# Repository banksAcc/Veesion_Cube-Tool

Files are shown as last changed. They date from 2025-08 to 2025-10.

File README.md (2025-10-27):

# Veesion Cube Tool

A compact hardware and software stack for estimating the pose of a 3D‑printed pen tip.  
An ESP32 inside the pen sends a BLE trigger; the PC listens for the event, grabs a frame from a camera and computes the pen pose from ArUco markers.







## Idea
<div style="display: flex; gap: 20px;">
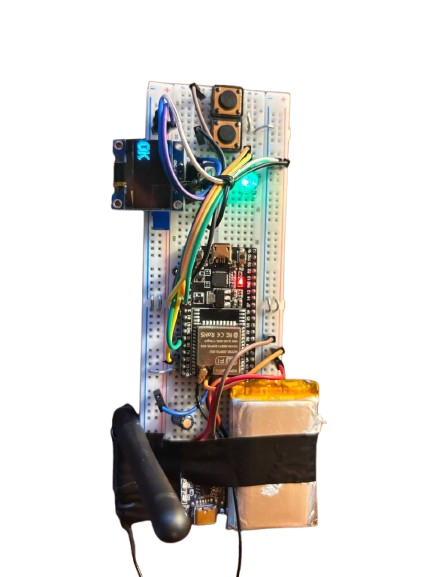
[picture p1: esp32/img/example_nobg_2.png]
Device
  
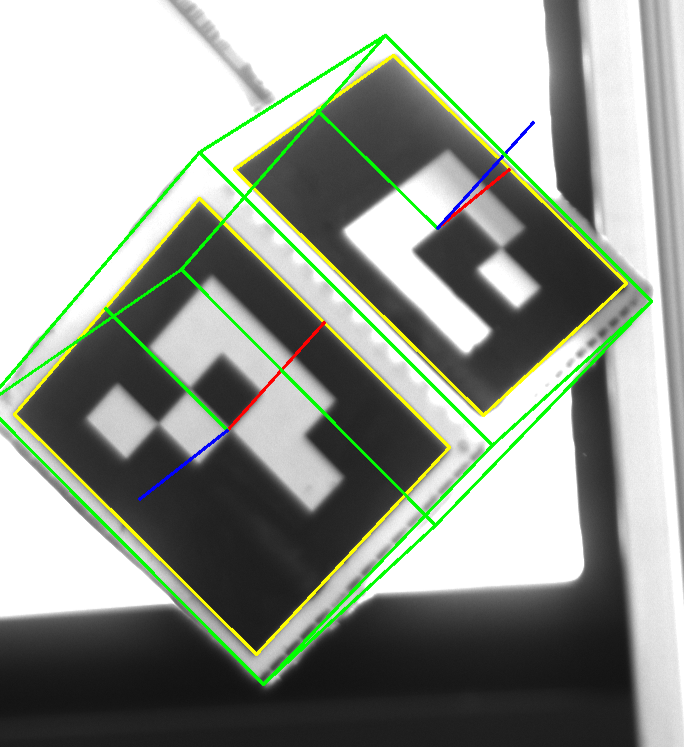
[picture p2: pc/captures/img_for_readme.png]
Cube After
  
</div>
<p align="center">
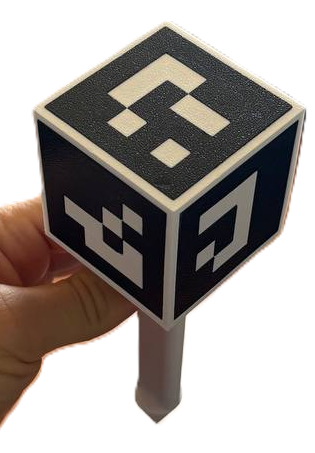
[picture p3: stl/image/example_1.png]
3D pen
  
</p>

## Prerequisites

### Hardware
- **ESP32 DevKit** (BLE + two buttons) to trigger the acquisition
- **Physical assembly**: 3D-printed pen/cube with 3–4 ArUco markers attached
- **Camera**: Basler camera with Pylon drivers installed or a compatible UVC webcam
- **Calibration target**: ChArUco board or checkerboard pattern

### Software
- **Python ≥3.10** and `pip` to install dependencies
- **ESP32 firmware toolchain**: Arduino IDE/CLI or PlatformIO (optional but recommended)
- **Basler Pylon drivers** (optional) for industrial camera integration
- Python libraries from [`pc/app/requirements.txt`](pc/app/requirements.txt)

## Repository structure
- [`esp32/`](esp32/) – BLE firmware for the pen, detailed in [`esp32/README.md`](esp32/README.md)
- [`pc/`](pc/) – PC-side application for capture and pose estimation, see [`pc/README.md`](pc/README.md)
- [`cube_minimal/`](cube_minimal/) – pose estimation library with dataset and tests
- [`cube_minimal/data/sample_dataset/`](cube_minimal/data/sample_dataset/) – sample images referenced in [Quick start](#quick-start)

## Workflow
1. Press a button on the pen. The ESP32 publishes a BLE notification.
2. The PC application receives the trigger and acquires an image from the selected camera.
3. ArUco markers on the cube are detected and the cube pose is estimated.
4. A fixed transform gives the pen‑tip pose, which can be logged or streamed.

### Pose result artifacts

Each capture session produces both a JSON summary and a CSV table beside the
session folder (e.g. `session_<start>__<end>_pose.json` / `.csv`). The JSON file
stores a list of frame objects containing:

* `tvec_tip`: Cartesian tip position expressed in metres relative to the camera.
* `wand_direction`: Normalised tip direction vector in camera coordinates.
* `euler_tip`: Tip orientation expressed as Z‑Y‑Z intrinsic Euler angles
  (`rz1`, `ry`, `rz2`) in radians.
* `tip_pose`: Convenience tuple `(x, y, z, rz1, ry, rz2)` merging position and
  orientation. Downstream consumers should prefer this when available.

The accompanying CSV mirrors the JSON content with one row per frame and the
columns: `frame_index`, `timestamp`, `ok`, `tip_x`, `tip_y`, `tip_z`, `tip_rz1`,
`tip_ry`, `tip_rz2`. Numerical values are emitted in metres/radians to ease data
analysis in spreadsheets or plotting tools.

## Quick start

### Set up the PC environment
```bash
cd pc
python -m venv .venv
source .venv/bin/activate
pip install -r app/requirements.txt
```
```powershell
cd pc
py -m venv .venv
. .\.venv\Scripts\Activate.ps1
pip install -r app\requirements.txt
```
> Tip: keep the virtual environment active for the next steps (`pytest`, CLI, PC application).

### Build & flash the ESP32 firmware
Follow the [Getting Started](esp32/README.md#getting-started) section of the firmware:

1. Install the **NimBLE-Arduino**, **Adafruit SSD1306**, and **Adafruit GFX** libraries via the Arduino Library Manager.
2. Wire the components as described in [`esp32/README.md`](esp32/README.md#connections).
3. Build and upload the project by selecting the **ESP32 Dev Module** board (Arduino IDE/CLI) or set up an equivalent PlatformIO project.

### Calibration and sample dataset
- Use the scripts in [`pc/calib/`](pc/calib/) to produce `calib_data.npz` (camera intrinsics) from a ChArUco/checkerboard target.
- For quick trials, point `capture.test_source_dir` to [`cube_minimal/data/sample_dataset/`](cube_minimal/data/sample_dataset/), which contains the sample images described in its [README](cube_minimal/data/README.md).

### Run the pipeline quickly
```bash
cd pc/app
python app.py
```
Configure [`config.yaml`](pc/app/config.yaml) before launching the application: set `ble.name_prefix` or `ble.addr`, choose the camera (`camera_type`, `camera_id`/`camera_serial`), and provide the calibration path (`pose.camera_calibration_npz`).

#### Simulated mode
For tests without physical hardware, set in `config.yaml`:

```yaml
capture:
  simulate_camera: true
  test_source_dir: "../cube_minimal/data/sample_dataset"
```
This mode replays sessions by reading the sample images through the same processing pipeline.

## Rapid validation
- **Python tests** (`cube_minimal`):
  ```bash
  cd pc
  source .venv/bin/activate        # Linux/macOS
  # PowerShell: . .\.venv\Scripts\Activate.ps1
  pytest ../cube_minimal/tests
  ```
- **Single-image estimation CLI**:
  ```bash
  python -m cube_minimal.cli.estimate_one --image cube_minimal/data/sample_dataset/example_1.png --camera cube_minimal/config/calib_data.npz --aruco_dict 4X4_50 --marker_size 0.055 --cube_size 0.060 --out overlay.png
  ```
- **Simulated PC session**: enable `capture.simulate_camera: true` as above and launch the application from `pc/app/`:
  ```bash
  python app.py
  ```
- **Static quality checks** (run from the repository root after activating the virtualenv):
  ```bash
  ruff check pc/app
  mypy
  ```
  Both tools read their configuration from `pyproject.toml` and warn about style or typing regressions.

## Further reading
- [Prerequisites](#prerequisites) and [Repository structure](#repository-structure) for a quick overview
- [`pc/README.md`](pc/README.md) – deep dive into the PC pipeline configuration and Basler parameters
- [`esp32/README.md`](esp32/README.md) – hardware details, LEDs, and buttons
- [`cube_minimal/README.md`](cube_minimal/README.md) – pose estimation API and CLI
- [`cube_minimal/data/README.md`](cube_minimal/data/README.md) – structure of the sample dataset

## Next steps
- Specchiare Marker Errato sul pennino; Review Pennino
- Calibrazione Estrinseca Dexter
- Sviluppo di un programma robot per lettura csv e spostamento braccio nella posizione desiderata

report di chiusura del lavoro
## License
All rights reserved.

This software and all associated files are the exclusive property of Angelo Milella - COMAU.
Unauthorized copying, modification, distribution, or use of this software, via any medium, is strictly prohibited.

For inquiries about licensing, please contact: <angelo_milella_dev@yahoo.com>.

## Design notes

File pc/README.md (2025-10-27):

# ESP32 BLE Trigger -> PC Capture & Pose Pipeline

## Overview
This directory hosts the Python application that listens for BLE triggers from an ESP32 device, captures images, and performs optional cube pose estimation.

## Features
- Start or stop capture sessions from a physical ESP32 button.
- Stream captured frames in-memory to the pose worker for low-latency processing.
- Optionally persist frames (raw images plus `_overlay` diagnostics) by enabling `capture.save_frames` and, if desired, `pose.save_overlay`.
- Support webcams or industrial cameras such as Basler via `pypylon`.

## Prerequisites
- Python 3.10 or newer available on the system `PATH`.
- `pip` for installing Python dependencies.
- Optional Basler Pylon drivers and the `pypylon` package when using Basler cameras.
- BLE tooling (BlueZ on Linux, native stack on Windows/macOS) to pair the ESP32.

## Project Structure
```
app/
  app.py               # application entry point
  ble_client.py        # BLE connection and message handling
  capture.py           # camera acquisition or simulated frame sourcing
  click_test.py        # quick script to validate BLE button callbacks
  config.yaml          # runtime configuration
  pose_worker.py       # asynchronous pose computation
  requirements.txt
  session_manager.py   # session lifecycle management

calib/                  # sample calibration data
captures/               # capture sessions written here
image_to_be_used/       # sample dataset for simulated mode
```

## Installation
Run the commands from the `pc/` directory.

### Linux/macOS (bash/zsh)
```bash
python3 -m venv .venv
source .venv/bin/activate
pip install -r app/requirements.txt
```

### Windows (PowerShell)
```powershell
python -m venv .venv
.\.venv\Scripts\Activate.ps1
pip install -r app\requirements.txt
```

Deactivate the virtual environment with `deactivate` when you are done.

## Quick Configuration
1. Copy `app/config.example.yaml` to `app/config.yaml` if the example file is available. Otherwise duplicate the existing `config.yaml` before editing.
2. For simulated runs, set `capture.simulate_camera: true` and point `capture.test_source_dir` to `../image_to_be_used` or another folder with sample frames.
3. For real hardware, set `capture.simulate_camera: false`, choose `capture.camera_type` (`webcam`, `ip`, `basler`, etc.), and configure `capture.camera_id`, `capture.camera_serial`, or `capture.camera_ip` as required.
4. Decide whether to persist frames by setting `capture.save_frames` (disabled by default to favour throughput).
5. Confirm `pose.camera_calibration_npz` points to a valid calibration file inside `calib/`.
6. Adjust logging preferences with `runtime.log_level` and `runtime.log_to_file` if you need more diagnostics.

## Execution
- Simulated mode (no camera): ensure `capture.simulate_camera: true`, then run
  ```bash
  python app/app.py
  ```
- Real camera mode: set `capture.simulate_camera: false`, install any manufacturer drivers (for Basler, install Pylon and `pip install pypylon`), then execute
  ```bash
  python app/app.py
  ```
- Quick BLE test: validate button presses and logging without the full pipeline using
  ```bash
  python app/click_test.py
  ```

## Test and Debug
- Each capture session writes a `session.log` file inside the session folder under `captures/`.
- Global logging can be enabled with `runtime.log_to_file: true`, producing `app.log` in the project root.
- Raise verbosity by setting `runtime.log_level` to `DEBUG`, then restart the application to reload the configuration.
- BLE connection states, capture errors, and pose worker issues are all reported in the logs for post-mortem analysis.

## Key Parameters
| Parameter | Section | Purpose | Example |
| --- | --- | --- | --- |
| `capture.frequency_ms` | `capture` | Interval between frame acquisitions in milliseconds. | `200` |
| `capture.simulate_camera` | `capture` | Toggle between simulated datasets and live cameras. | `true` |
| `capture.save_frames` | `capture` | Enable asynchronous persistence of raw frames. | `false` |
| `pose.save_overlay` | `pose` | Persist diagnostic overlays next to raw frames (`*_overlay.tiff`). | `true` |
| `capture.frame_queue_size` | `capture` | Number of frames buffered between capture and pose processing. | `4` |
| `capture.test_source_dir` | `capture` | Directory for sample frames when simulating. | `../image_to_be_used` |
| `pose.method` | `pose` | Select the pose solver (`cube`, `custom`). | `cube` |
| `pose.max_parallel_jobs` | `pose` | Limit concurrent pose computations. | `3` |
| `runtime.log_level` | `runtime` | Set logging verbosity (`DEBUG`, `INFO`, `WARNING`, `ERROR`). | `INFO` |
| `runtime.log_to_file` | `runtime` | Enable writing aggregated logs to `app.log`. | `false` |

Pose results are saved alongside session folders. Refer to `../cube_minimal/README.md` for details on interpreting the cube pose output and validating calibration.

## License
All rights reserved.

This software and all associated files are the exclusive property of Angelo Milella - COMAU.
Unauthorized copying, modification, distribution, or use of this software, via any medium, is strictly prohibited.

For inquiries about licensing, please contact: <angelo_milella_dev@yahoo.com>.

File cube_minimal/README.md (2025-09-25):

# cube_pose - Stima posa cubo da marker ArUco

Mini-moduli riutilizzabili per:
- rilevare marker ArUco,
- stimare la posa dei singoli marker (IPPE SQUARE),
- ricostruire la posa di un **cubo** (centro + orientazione) usando 1..3 marker visibili,
- disegnare overlay di diagnostica.

> **Convenzione**: la Z del **marker** (asse blu) esce dal piano del marker (verso la camera);
> la Z del **cubo** è definita uscente dal cubo e per costruzione corrisponde a `-Z_marker` di una delle facce.

## Installazione

Da una shell nella radice del progetto:

```bash
pip install -e .
```

Oppure, per un installazione standard senza modifica del codice:

```bash
pip install .
```

Entrambi i comandi leggono le dipendenze elencate in `pyproject.toml` (`opencv-python` e `numpy`).

### Note su OpenCV
- Servono i moduli extra (ArUco incluso), assicurati che `opencv-python` sia almeno la versione `>=4.7`; in alternativa installa `opencv-contrib-python`.
- Su Linux potrebbe essere necessario avere installate le librerie di sistema per il supporto a GUI/video, ad esempio `sudo apt install libgl1`.
- Su Windows e macOS i wheel ufficiali includono gia il supporto ArUco.

## API principale

```python
from cube_minimal.cube_pose.api import estimate_cube_from_image

res = estimate_cube_from_image(
    image_or_path="cube_minimal/data/sample_dataset/example_1.png",
    camera_npz="cube_minimal/config/calib_data.npz",
    aruco_dict="4X4_50",
    marker_size=0.055,  # metri (lato del quadrato nero!)
    cube_size=0.060,    # metri
    pair_strategy="first",    # oppure "max_angle"
    return_overlay=True
)

tvec = res["tvec"]   # (3,) centro cubo in camera (m)
rvec = res["rvec"]   # (3,1) Rodrigues del cubo
R    = res["R"]      # (3,3) matrice di rotazione
quat = res["quat"]   # (4,) w,x,y,z
img  = res["overlay"]
```

### Output in sintesi

| Chiave | Shape | Contenuto |
| --- | ----- | --- |
| `tvec` | `(3,)` | Centro del cubo espresso nel frame camera (metri). |
| `rvec` | `(3,1)` | Vettore di rotazione in forma di Rodrigues relativo al cubo. |
| `R` | `(3,3)` | Matrice di rotazione del cubo, colonne = assi del cubo nel frame camera. |
| `quat` | `(4,)` | Quaternione `(w, x, y, z)` del cubo rispetto alla camera. |
| `overlay` | `H x W x 3` | Immagine originale con overlay diagnostico (se richiesto). |

## Dataset di esempio
- Le immagini di test sono in `cube_minimal/data/sample_dataset`.
- Il README dedicato ai dati contiene dettagli su calibrazione e convenzioni: vedi [`cube_minimal/data/README.md`](data/README.md).
- Per provare velocemente l API, usa il file `cube_minimal/data/sample_dataset/example_1.png` insieme alla calibrazione `cube_minimal/config/calib_data.npz`.

## CLI

Esempi assumendo il repository clonato localmente.

### Linux/macOS
```bash
python -m cube_minimal.cli.estimate_one \
    --image cube_minimal/data/sample_dataset/example_1.png \
    --camera cube_minimal/config/calib_data.npz \
    --aruco_dict 4X4_50 \
    --marker_size 0.055 \
    --cube_size 0.060 \
    --pair_strategy first \
    --out cube_minimal/data/sample_dataset/overlay.png \
    --show
```

### Windows (PowerShell)
```powershell
python -m cube_minimal.cli.estimate_one `
    --image cube_minimal\data\sample_dataset\example_1.png `
    --camera cube_minimal\config\calib_data.npz `
    --aruco_dict 4X4_50 `
    --marker_size 0.055 `
    --cube_size 0.060 `
    --pair_strategy first `
    --out cube_minimal\data\sample_dataset\overlay.png `
    --show
```

### Parametri principali
- `aruco_dict`: stringa della famiglia di marker (es. `4X4_50`, `5X5_100`). Deve corrispondere ai marker nel dataset.
- `marker_size`: lato del quadrato nero del marker in metri. Influisce direttamente sulla scala della posa.
- `cube_size`: lato del cubo fisico in metri. Determina il posizionamento del centro rispetto ai marker.
- `pair_strategy`: regolazione della fusione tra facce (`first` = usa la prima coppia trovata, `max_angle` = privilegia la coppia con facce piu ortogonali).

## Strategia di stima (riassunto)

1. **Detection** ArUco -> corner 2D (ordine: top-left, top-right, bottom-right, bottom-left).
2. **Pose marker** con `SOLVEPNP_IPPE_SQUARE` (viene scelta la soluzione a errore minimo).
3. **Centro cubo** da singolo marker: `t_marker - Z_marker * L/2`.
4. **Centro cubo finale** = media dei centri (1..3 marker).
5. **Orientazione cubo**:
   - Con `>=2` marker: `Z_cubo = -Z_marker_1`, `X_cubo` allineato alla seconda faccia (proiettato sul piano ortogonale a `Z_cubo`), `Y_cubo = Z_cubo x X_cubo`.
   - Con `1` marker: `Z_cubo = -Z_marker`, `X/Y` ricavati dal piano della stessa faccia.
6. Output: `tvec`, `rvec` (Rodrigues), `R`, `quat`.

## Requisiti
- `opencv-python`
- `numpy`

## Note importanti
- `marker_size` deve essere il lato del quadrato nero (no bordo bianco).
- Il file `.npz` della camera deve contenere `K`/`cameraMatrix` e `dist`/`distCoeffs`.
- Se usi piu marker e vuoi piu robustezza, prova `pair_strategy="max_angle"`.

## Test

I test si trovano nella cartella `tests`. Dopo aver installato il progetto (e `pytest`), esegui:

```bash
pytest tests
```

Oppure:

```bash
python -m pytest tests
```

Assicurati che l ambiente includa eventuali asset necessari (dataset di sample e parametri camera).

## TODO (prossimi sviluppi)
- Test automatici piu estesi (copertura funzioni in `cube_pose`).
- Migliorare la stima del centro (mediana o pesi per facce di qualita diversa).
- Metriche di coerenza addizionali (angolo tra normali, deviazione di riproiezione).

## License
All rights reserved.

This software and all associated files are the exclusive property of Angelo Milella - COMAU.
Unauthorized copying, modification, distribution, or use of this software, via any medium, is strictly prohibited.

For inquiries about licensing, please contact: <angelo_milella_dev@yahoo.com>.

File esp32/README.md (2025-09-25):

# ESP32 BLE Controller with RGB LED and OLED Display

Firmware for an ESP32 DevKit that exposes a BLE interface to trigger image
capture on a PC. It includes user feedback via a common-anode RGB LED and a
128x64 I2C SSD1306 OLED display, plus two physical buttons.

## Prerequisiti software

- **Arduino IDE 2.3.x**: https://www.arduino.cc/en/software
- **Pacchetto schede ESP32 2.0.14** (aggiungi `https://dl.espressif.com/dl/package_esp32_index.json` in File > Preferenze > URL per Gestore Schede)
- **Librerie consigliate** (Library Manager):
  - NimBLE-Arduino 1.4.1 — https://github.com/h2zero/NimBLE-Arduino
  - Adafruit SSD1306 2.5.13 — https://github.com/adafruit/Adafruit_SSD1306
  - Adafruit GFX Library 1.11.9 — https://github.com/adafruit/Adafruit-GFX-Library
- **arduino-cli 0.35.x** (facoltativo, per build da terminale): https://arduino.github.io/arduino-cli/latest/installation/
- **PlatformIO Core 6.1.x** (facoltativo, VS Code o CLI): https://docs.platformio.org/en/latest/core/installation.html

## Hardware

- **ESP32 DevKit** (ESP-WROOM-32)
- **RGB LED (common anode)** with resistors on the cathodes
- **SSD1306 OLED** display (128x64, I2C address 0x3C)
- **Two push buttons** using `INPUT_PULLUP`

### Connections

- **OLED**: SDA -> GPIO21, SCL -> GPIO22, VCC=3.3V, GND
- **LED RGB**: R=GPIO15, G=GPIO5, B=GPIO4 (anode to +5V)
- **Buttons**: BTN_EVENT -> GPIO16, BTN_BLE -> GPIO17

## Behaviour

### LED States

- **ADV (advertising)**: blue breathing effect
- **CONNECTED**: solid green
- **ARMING (BTN17 press)**: fast yellow blink
- **SENDING**: solid dim yellow
- **EVENT_RED**: red while BTN16 is pressed and connected
- **OFF**: LED off

### OLED Display

- **BLE ON (advertising)**: shows `STATUS: FREE` with spinner
- **CONNECTED**: shows `STATUS: OK`
- **DISCONNECTED/OFF**: shows `BLE OFF`, then turns off after 1 s
- **SENDING**: shows `Sending...`
- **BLE RX messages**: `COMPUTATION START` displays a banner, `COMPUTATION END` removes it

### Buttons

- **BTN_BLE (GPIO17)**:
  - Long press >= 4 s -> toggle BLE on/off (disconnect if connected)
  - Short press < 4 s -> disconnect and return to advertising
- **BTN_EVENT (GPIO16)**:
  - Press -> send `START\n`, LED goes red, display `Sending...`
  - Release -> send `END\n`

## Software Structure

- `main.ino` orchestrates buttons, BLE and UI
- `config.h` pin definitions and parameters
- `LedManager.*` RGB LED effects (inverted for common anode)
- `DisplayManager.*` SSD1306 display management
- `BleManager.*` NimBLE-Arduino wrapper (UART-like service)
- `Buttons.h` debounce and short/long press detection

## Notes

- LEDC PWM: 5 kHz, 12-bit resolution, global brightness limited to 10%
- Display powers off physically when BLE is off
- BLE messages are trimmed and uppercased for robustness

## Apertura del progetto

**Arduino IDE**

1. Avvia Arduino IDE e verifica che il pacchetto ESP32 sia installato (Tools > Board > Boards Manager).
2. Seleziona `File > Apri...` e punta alla cartella `esp32/src` (contiene `main.ino`).
3. Imposta `Tools > Board > ESP32 Dev Module` (o la scheda corrispondente al tuo DevKit).
4. Usa `Sketch > Include Library > Manage Libraries...` per installare/aggiornare le librerie consigliate alle versioni indicate.
5. Collega l'ESP32, scegli la porta corretta da `Tools > Port` e compila o carica normalmente.

**PlatformIO (VS Code o CLI)**

1. Apri la cartella `esp32` come workspace.
2. Se il file `platformio.ini` non esiste, crealo nella root `esp32` con il contenuto seguente:

   ```ini
   [env:esp32dev]
   platform = espressif32
   board = esp32dev
   framework = arduino
   monitor_speed = 115200
   lib_deps =
     h2zero/NimBLE-Arduino@^1.4.1
     adafruit/Adafruit SSD1306@^2.5.13
     adafruit/Adafruit GFX Library@^1.11.9
   ```

3. Con PlatformIO IDE scegli `Open Project` e seleziona `esp32`.
4. Da terminale puoi inizializzare automaticamente con `pio project init --board esp32dev` (sovrascrivera un `platformio.ini` gia presente solo se specificato con `--overwrite`).

## Build e caricamento

**Arduino CLI**

```powershell
arduino-cli core install esp32:esp32
arduino-cli compile --fqbn esp32:esp32:esp32 esp32/src
arduino-cli upload --fqbn esp32:esp32:esp32 -p COM5 esp32/src
```

Sostituisci `COM5` con la porta seriale rilevata (`arduino-cli board list`). Aggiungi `--build-path build/esp32` se vuoi un percorso di output dedicato.

**PlatformIO**

```powershell
pio run
pio run -t upload
```

Usa `pio device list` per trovare la porta, oppure specifica `upload_port = COM5` in `platformio.ini`.

## Monitor seriale e logging BLE

**Console seriale**

```powershell
arduino-cli monitor -p COM5 -c baudrate=115200
pio device monitor -b 115200
screen /dev/ttyUSB0 115200
```

**Log BLE**

- App mobili come nRF Connect o LightBlue consentono di verificare advertising e notifiche.
- Da PC puoi usare la libreria Python `bleak` per ricevere/loggare i messaggi BLE UART.

Esempio di script minimale (Linux/macOS/Windows, sostituisci `DEVICE_ADDRESS` con l'indirizzo del tuo ESP32):

```python
import asyncio
from bleak import BleakClient

UART_TX = "6e400003-b5a3-f393-e0a9-e50e24dcca9e"  # Notify characteristic
UART_RX = "6e400002-b5a3-f393-e0a9-e50e24dcca9e"  # Write characteristic

async def main():
    async with BleakClient("DEVICE_ADDRESS") as client:
        await client.start_notify(UART_TX, lambda _, data: print("[RX]", data.decode().strip()))
        await client.write_gatt_char(UART_RX, b"START\n")
        await asyncio.sleep(5)
        await client.write_gatt_char(UART_RX, b"END\n")

asyncio.run(main())
```

## Personalizzazione via `config.h`

Il file `esp32/src/config.h` centralizza pin e parametri principali:

- Aggiorna `PIN_LED_R`, `PIN_LED_G`, `PIN_LED_B` per adeguare il cablaggio del tuo LED.
- Modifica `PIN_BTN_EVENT`, `PIN_BTN_BLE` e `BLE_LONG_MS` per pulsanti e durata del long press.
- Cambia `I2C_SDA_PIN`, `I2C_SCL_PIN`, `OLED_ADDR`, `OLED_WIDTH`, `OLED_HEIGHT` se usi bus o display differenti.
- Regola `LED_BRIGHTNESS`, `LED_PWM_FREQ` e `LED_PWM_RES` se desideri effetti luminosi differenti.

Per personalizzare il nome BLE trasmesso:

1. Aggiungi in `config.h` (sotto gli altri define):

   ```cpp
   #define BLE_DEVICE_NAME "ESP32-RGB-BLE"
   ```

2. Sostituisci in `esp32/src/main.ino` la riga `BLE.begin("ESP32-RGB-BLE");` con `BLE.begin(BLE_DEVICE_NAME);`.

In questo modo potrai aggiornare il nome pubblicato senza toccare altre parti del codice.

## Verifica BLE con un client

1. Metti l'ESP32 in advertising (LED blu pulsante, display `STATUS: FREE`).
2. Avvia uno scanner BLE (nRF Connect, LightBlue, `bleak` con `python -m bleak discover`).
3. Verifica che il nome trasmesso corrisponda a quello impostato in configurazione.
4. Connettiti e osserva le notifiche sulla caratteristica UART (`6e400003-...`). I messaggi `START`/`END` devono apparire durante la pressione del pulsante evento.
5. Invia `START\n` e `END\n` dal client per verificare la gestione RX (sul Serial Monitor vedrai i log `[BLE] RX: ...`).

## Test rapido

1. Collega LED e display secondo lo schema della sezione Hardware, poi alimenta l'ESP32 via USB.
2. All'avvio il LED deve respirare in blu e l'OLED mostra `STATUS: FREE` con spinner.
3. Premendo il pulsante evento il LED diventa rosso, il display mostra `Sending...` e il log seriale riporta `[BLE] TX: START` / `[BLE] TX: END`.
4. Premendo a lungo il pulsante BLE (>= 4 s) il modulo si disconnette: LED spento, display `BLE OFF` che dopo 1 s si spegne.
5. Rilascia il pulsante BLE per tornare in advertising e verifica da un client BLE che le notifiche vengano nuovamente ricevute.

## Getting Started

1. Installa le librerie tramite Library Manager (`NimBLE-Arduino`, `Adafruit SSD1306`, `Adafruit GFX`).
2. Cabla i componenti come descritto sopra.
3. Compila e carica usando `ESP32 Dev Module` o l'ambiente PlatformIO.
4. Connettiti con un client BLE per inviare e ricevere messaggi.

## License
All rights reserved.

This software and all associated files are the exclusive property of Angelo Milella - COMAU
Unauthorized copying, modification, distribution, or use of this software, via any medium, is strictly prohibited.

For inquiries about licensing, please contact: <angelo_milella_dev@yahoo.com>.

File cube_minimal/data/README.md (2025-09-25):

# Sample dataset

Sample images for exercising the `cube_minimal` API/CLI.
The `example_*.png` files show a cube with ArUco markers ready for pose estimation.

## Add new images

1. Copy new images into this folder (`cube_minimal/data/`).
2. Use descriptive filenames (e.g. `new_01.png`).
3. Call the CLI with the full image path via `--image`:

```bash
python -m cube_minimal.cli.estimate_one --image cube_minimal/data/new_01.png --camera cube_minimal/config/calib_data.npz --marker_size 0.022 --cube_size 0.06
```

Adjust `--marker_size` (marker side length in meters) and `--cube_size` (cube edge length in meters) to match your scene. Example calibration files live in `cube_minimal/config/` (e.g. `calib_data.npz`).

Images can also be consumed directly from the API by reusing the same absolute paths.

## Quick try

1. Copy or export a new test image into `cube_minimal/data/`. Ensure the markers are clearly visible and that the physical dimensions match the `marker_size` and `cube_size` values you will pass.
2. Run the CLI to estimate the pose and optionally display/save the result:

```bash
python -m cube_minimal.cli.estimate_one --image cube_minimal/data/example_01.png --camera cube_minimal/config/calib_data.npz --marker_size 0.022 --cube_size 0.06 --show --out cube_minimal/data/example_01_result.json
```

- `--show` opens a window that overlays the projected cube onto the input image.
- `--out` stores pose matrices, error metrics, and other outputs in the provided JSON file.

3. From Python code you can perform the same estimation using the high-level helper:

```python
from cube_minimal.cli import estimate_cube_from_image

result = estimate_cube_from_image(
    image_path="cube_minimal/data/example_01.png",
    camera_path="cube_minimal/config/calib_data.npz",
    marker_size=0.022,
    cube_size=0.06,
    show=True,
)
print(result.pose)
```

`estimate_cube_from_image` returns an object with the pose transform and diagnostic details, reusing the same images and calibration files as the CLI.

To plug these images into the PC pipeline in simulated mode, see the [main README](../README.md).

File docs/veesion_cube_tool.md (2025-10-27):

# Documento di sintesi del sistema Veesion Cube Tool

## Visione complessiva
Abbiamo progettato il Veesion Cube Tool come una piattaforma integrata hardware–software capace di stimare la posa tridimensionale della punta di un pennino dotato di marker ArUco. La catena inizia da un modulo **ESP32** incapsulato nell'oggetto fisico e termina nella pipeline software su PC che acquisisce fotogrammi, esegue la stima di posa e produce artefatti analitici (JSON, CSV, overlay). Il presente documento funge da base strutturata per la redazione della documentazione ufficiale: raccoglie le motivazioni progettuali, i componenti materiali e digitali, il flusso di elaborazione, le librerie riutilizzabili e gli strumenti ausiliari.

## Hardware e oggetto fisico
### Penna intelligente con ESP32
Abbiamo alloggiato un **ESP32 DevKit** all'interno di un corpo penna/cubo stampato in 3D. Il firmware, descritto in dettaglio in [`esp32/README.md`](../esp32/README.md), gestisce:
- una coppia di pulsanti (`BTN_EVENT`, `BTN_BLE`) per generare notifiche BLE (`START`/`END`) e per abilitare o disabilitare la radio;
- un LED RGB a catodo comune con codifica a stati (advertising blu, connessione verde, invio evento rosso/giallo);
- un display OLED SSD1306 per feedback testuale, utile durante sessioni di laboratorio;
- un protocollo BLE UART‐like implementato tramite NimBLE che invia comandi al PC e riceve notifiche di stato (`COMPUTATION START`/`END`).
I dettagli di cablaggio (GPIO21/22 per I²C, GPIO4/5/15 per il LED, GPIO16/17 per i pulsanti) e le note operative sono raccolti nel README citato. Il firmware vive nel sorgente [`esp32/src`](../esp32/src).

### Marcatori ArUco e corpo fisico
Il pennino monta un cubo con 5 marker ArUco, modellato tramite i file STL presenti in [`stl/`](../stl/). La geometria garantisce una distanza nota tra il centro del cubo e la punta: ciò alimenta la trasformazione rigida utilizzata dal PC per derivare la posa del tip partendo dal cubo. Le immagini dimostrative (`stl/image/example_1.png`, `example_2.png`) illustrano l'assemblaggio finale.

### Calibrazione e dataset di riferimento
Per le validazioni in laboratorio utilizziamo un target ChArUco/checkerboard per stimare gli intrinseci della camera. I file di configurazione campione sono in [`cube_minimal/config`](../cube_minimal/config) e [`pc/calib`](../pc/calib). Il dataset di immagini statiche usato nelle simulazioni e nei test è in [`cube_minimal/data/sample_dataset`](../cube_minimal/data/sample_dataset) e viene richiamato sia dalla CLI sia dal PC app in modalità `simulate_camera`.

## Pipeline software su PC
### Architettura generale
La directory [`pc/app`](../pc/app) ospita l'applicazione principale. Il flusso è orchestrato da tre componenti principali:
1. **Client BLE** – [`ble_client.py`](../pc/app/ble_client.py) scandisce o usa l'indirizzo fornito in configurazione, si connette all'ESP32 e inoltra i messaggi `START`/`END` al gestore di sessione. Lo stesso modulo mantiene un canale asincrono per inviare messaggi di ritorno verso l'hardware (ad esempio gli eventi `COMPUTATION START/END`).
2. **Session Manager** – [`session_manager.py`](../pc/app/session_manager.py) gestisce il ciclo di vita di ogni acquisizione. Alla ricezione di `START` crea un oggetto `Session` che sceglie il backend di cattura (`OpenCvCapture`, `PylonCapture` o `TestCapture`) in base alla configurazione (`capture.simulate_camera`). I fotogrammi vengono salvati facoltativamente e, soprattutto, vengono trasferiti in memoria a valle tramite `asyncio.Queue` sotto forma di `FramePacket` definiti in [`stream.py`](../pc/app/stream.py).
3. **Pose Worker** – [`pose_worker.py`](../pc/app/pose_worker.py) consuma la coda asincrona di pacchetti e invoca l'API di stima del cubo offerta dalla libreria `cube_minimal`. L'architettura multi‐thread (queue in memoria + `ThreadPoolExecutor`) ci consente di decouplare l'acquisizione dalla computazione mantenendo bassa la latenza.

Il file [`app.py`](../pc/app/app.py) collega le componenti precedenti, avviando l'event loop, la sessione BLE e la coda BLE per comunicare con il dispositivo. Il modulo [`config_models.py`](../pc/app/config_models.py) definisce la struttura tipizzata della configurazione (`AppConfig`), garantendo la validazione dei parametri presenti in [`config.yaml`](../pc/app/config.yaml).

### Flusso di una sessione
Quando l'ESP32 invia `START`, `SessionManager` crea una cartella `session_<timestamp>` con relativo `session.log`, lancia un thread di acquisizione e pone i `FramePacket` in coda. I pacchetti contengono frame BGR, nome file canonico, timestamp (sia float sia ISO) ed eventuale destinazione su disco se `capture.save_frames` è abilitato. Il worker di posa legge i pacchetti, invoca `_process_cube_frame` e popola una struttura `results` che verrà serializzata a fine sessione.

Alla ricezione di `END`, `SessionManager` chiude la sessione, notifica il worker tramite `PoseEndMessage` e attende la flush finale della coda. Il worker scrive due artefatti centrali:
- un JSON `<session>_pose.json` con tutti i frame elaborati (posizione e orientazione cubo, eventuali pose della punta);
- un CSV `<session>_pose.csv` con intestazioni `frame_index,timestamp,ok,tip_x,...,tip_rz2`, dove gli angoli Euler sono espressi in radianti secondo la convenzione intrinseca Z–Y–Z (funzione `_rotation_matrix_to_euler_zyz`).
Durante l'elaborazione il worker invia messaggi BLE `BLE_COMPUTATION_START/END` che il firmware può visualizzare sul display.

### Pipeline in memoria
Abbiamo scelto di mantenere l'intero flusso tra cattura e stima all'interno della RAM fino al punto di serializzazione finale. La classe `Session` spinge i frame in `asyncio.Queue` con capacità configurabile (`capture.frame_queue_size`); il worker li elabora in thread separato (`asyncio.to_thread`) e rilascia esplicitamente il riferimento all'immagine (`packet.frame = None`) subito dopo aver generato i risultati, evitando accumuli. Questa architettura minimizza l'I/O su disco e rende possibile la modalità `capture.save_frames = false` in cui nessun frame intermedio viene scritto.

## Libreria `cube_minimal`
### Struttura e API
La libreria, documentata in [`cube_minimal/README.md`](../cube_minimal/README.md), espone un'API ad alto livello tramite [`cube_pose/api.py`](../cube_minimal/cube_minimal/cube_pose/api.py). La funzione `estimate_cube_from_image` accetta un'immagine o un percorso, la calibrazione (`.npz` contenente `K` e `dist`), la dimensione dei marker e del cubo e una strategia di aggregazione delle facce (`pair_strategy`). Il flusso interno è:
1. caricamento dell'immagine e degli intrinseci (`load_camera`);
2. rilevazione ArUco (`detect_markers` in [`aruco_detect.py`](../cube_minimal/cube_minimal/cube_pose/aruco_detect.py));
3. stima della posa dei singoli marker con IPPE (`estimate_marker_poses` in [`marker_pose.py`](../cube_minimal/cube_minimal/cube_pose/marker_pose.py));
4. ricostruzione della posa del cubo a partire da 1–3 facce (`estimate_cube_pose` in [`cube_pose.py`](../cube_minimal/cube_minimal/cube_pose/cube_pose.py));
5. generazione di strutture derivate (matrice di rotazione, quaternione, overlay diagnostico).

### Filtro marker e gestione outlier
Per stabilizzare l'uso dei marker nel tempo abbiamo introdotto il filtro opzionale [`MarkerFilter`](../cube_minimal/cube_minimal/cube_pose/filtering/marker_filter.py). Quando attivo (`active_marker_filter` nella configurazione), il filtro:
- scarta le detezioni sotto una soglia di area proiettata (`area_threshold_px`), utile per rimuovere marker troppo inclinati o parzialmente visibili;
- rileva inversioni spurie dell'asse Z tra frame consecutivi. Se `try_adj_marker` è `True`, eseguiamo un flip controllato della posa (`_flip_pose_z`) anziché scartare il marker;
- mantiene uno stato interno per ogni marker (`_MarkerState`) memorizzando quota Z e area per poter stabilire quando una misura è incoerente.
Il risultato del filtro (`MarkerFilterResult`) viene propagato alla pipeline PC così da tracciare marker scartati/corretti nel JSON finale.

### Calcolo della punta e orientazione
`PoseWorker` non si limita alla posa del cubo: la funzione `_compute_wand_tip` combina le normali delle facce associate a direzioni note (`wand_directions` in configurazione) e, applicando l'offset `wand_offset_m`, ricostruisce la posizione della punta rispetto al centro del cubo. La matrice di rotazione della punta viene derivata con `_compute_tip_rotation`, scegliendo un asse X coerente con il cubo e ortogonale alla direzione della bacchetta; da qui calcoliamo gli Euler ZYZ, memorizzati sia in `euler_tip` sia nel vettore `tip_pose` (posizione + angoli) serializzato nel CSV.

### Strumenti di visualizzazione
Per l'analisi qualitativa e le presentazioni, `cube_minimal` offre funzioni di overlay in [`cube_pose/viz.py`](../cube_minimal/cube_minimal/cube_pose/viz.py):
- `draw_marker_outline` traccia il contorno delle facce rilevate;
- `draw_small_axes` visualizza gli assi locali del marker o del cubo;
- `draw_wirecube` proietta un reticolo del cubo nel piano immagine;
- `project_points_camframe` consente di verificare la proiezione di punti 3D nel frame camera.
Quando `estimate_cube_from_image` viene invocata con `return_overlay=True`, queste funzioni generano un'immagine annotata che il worker può salvare se `capture.save_frames` è attivo. L'overlay viene salvato accanto al TIFF originale usando il suffisso `_overlay` quando `pose.save_overlay` è abilitato.

## Output dati e logging
Ogni sessione produce:
- cartella `session_*` con log di cattura (`session.log`) e, se richiesto, i frame originali (`.tiff`) più le versioni annotate `*_overlay.tiff`;
- file JSON/CSV di posa nel percorso radice dell'app (`captures/` o directory configurata). Il formato CSV è pensato per integrazione con strumenti di robotica o analisi offline, mentre il JSON conserva tutti i dettagli (inclusi vettori `rvec`, `tvec`, numero di marker, info del filtro).
Il sistema registra inoltre log globali (`app.log` se `runtime.log_to_file` è `true`) e log per categoria (`POSE`, `SESSION`, `CAPTURE`) accessibili via console.

## Modalità operative e test
La configurazione [`config.yaml`](../pc/app/config.yaml) controlla frequenza di acquisizione, tipo di camera, dimensione delle code e attivazione del filtro marker. Possiamo eseguire:
- **Modalità simulata**: `capture.simulate_camera: true` e `capture.test_source_dir` puntato al dataset di esempio. Il backend [`TestCapture`](../pc/app/capture.py) riproduce le immagini sequenzialmente.
- **Modalità hardware**: `capture.simulate_camera: false`, backend [`OpenCvCapture`](../pc/app/capture.py) o [`PylonCapture`](../pc/app/capture.py) per camere Basler tramite `pypylon`.
- **Test unitari**: `pytest` nella cartella [`cube_minimal/tests`](../cube_minimal/tests) per validare funzioni di stima e filtri.

## Conclusione
Abbiamo costruito un ecosistema coerente in cui hardware, pipeline software e libreria algoritmica cooperano per fornire una stima di posa accurata e tracciabile della punta del pennino. La struttura modulare e la distinzione netta tra acquisizione, elaborazione e visualizzazione ci consentono di evolvere ciascun elemento (nuovi marker, nuovi algoritmi di smoothing, integrazione con robot) mantenendo stabilità operativa e tracciabilità dei dati. Questo documento rappresenta la base narrativa e tecnica per l'espansione verso una documentazione ufficiale completa.

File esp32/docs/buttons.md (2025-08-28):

# Button Handling

`Buttons.h` implements a simple event model for button presses:

- `fell` – HIGH→LOW transition (button pressed)
- `rose` – LOW→HIGH transition (button released)
- `longPress` – emitted once when the button stays pressed for `longMs`
- `isDown` – current state (LOW when pressed)

Example with `longMs = 500`:

```
time (ms): 0    50   550   800
level    : HIGH \____LOW____/ HIGH
              fell longPress  rose
```

`longPress` is fired only once for each press when `isDown` remains LOW for the
specified duration.

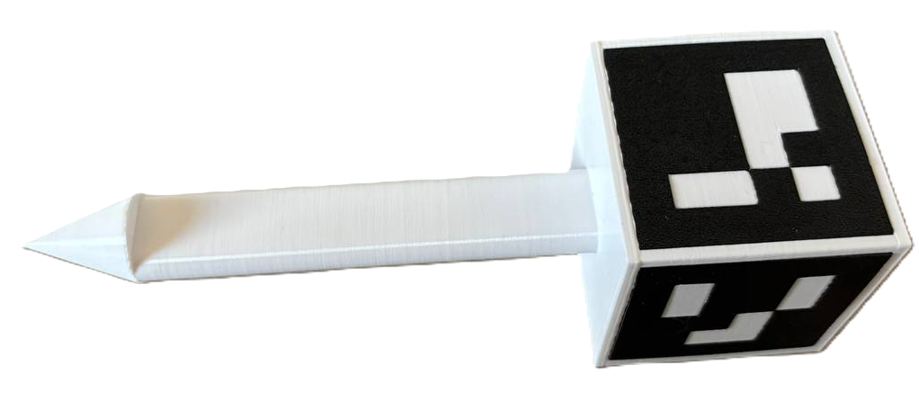
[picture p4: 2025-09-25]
stl/image/example_2.png

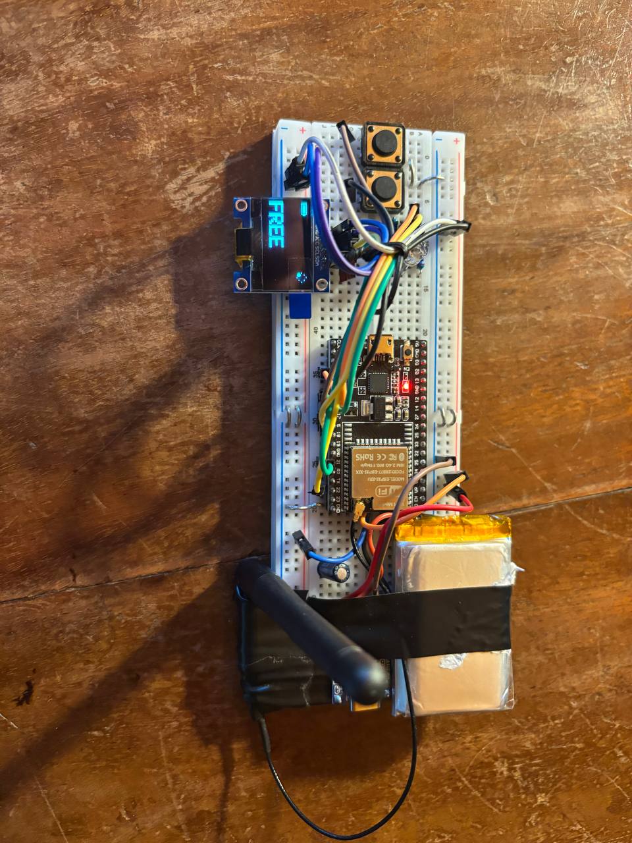
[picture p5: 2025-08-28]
esp32/img/example_3.jpg

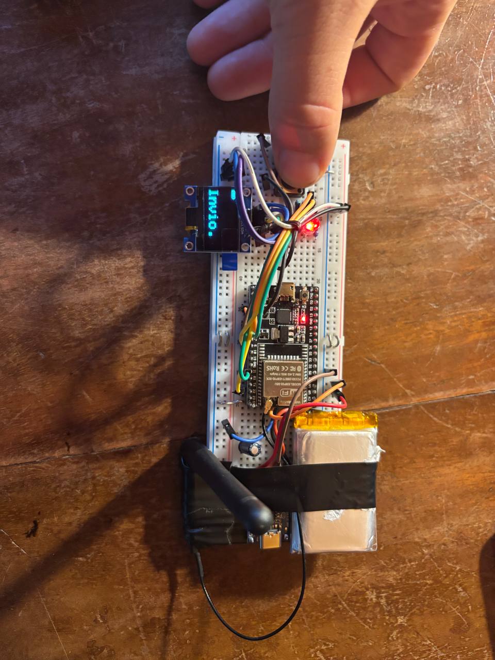
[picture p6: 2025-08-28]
esp32/img/example_4.jpg

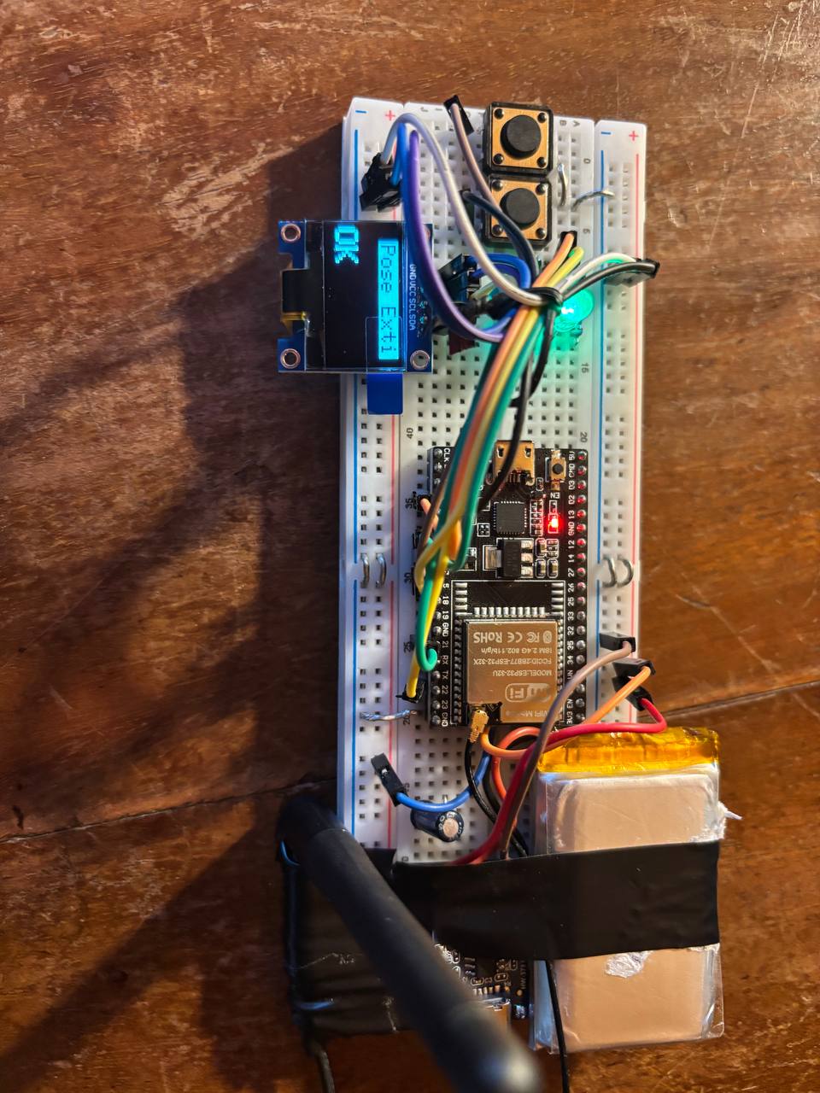
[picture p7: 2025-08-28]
esp32/img/example_1.jpg

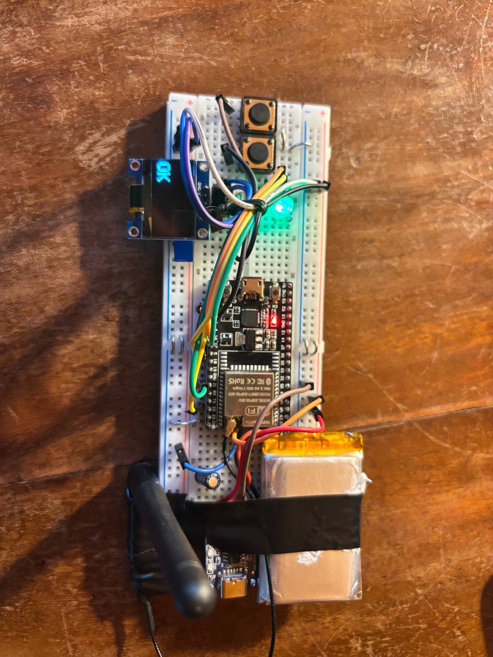
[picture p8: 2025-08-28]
esp32/img/example_2.jpg

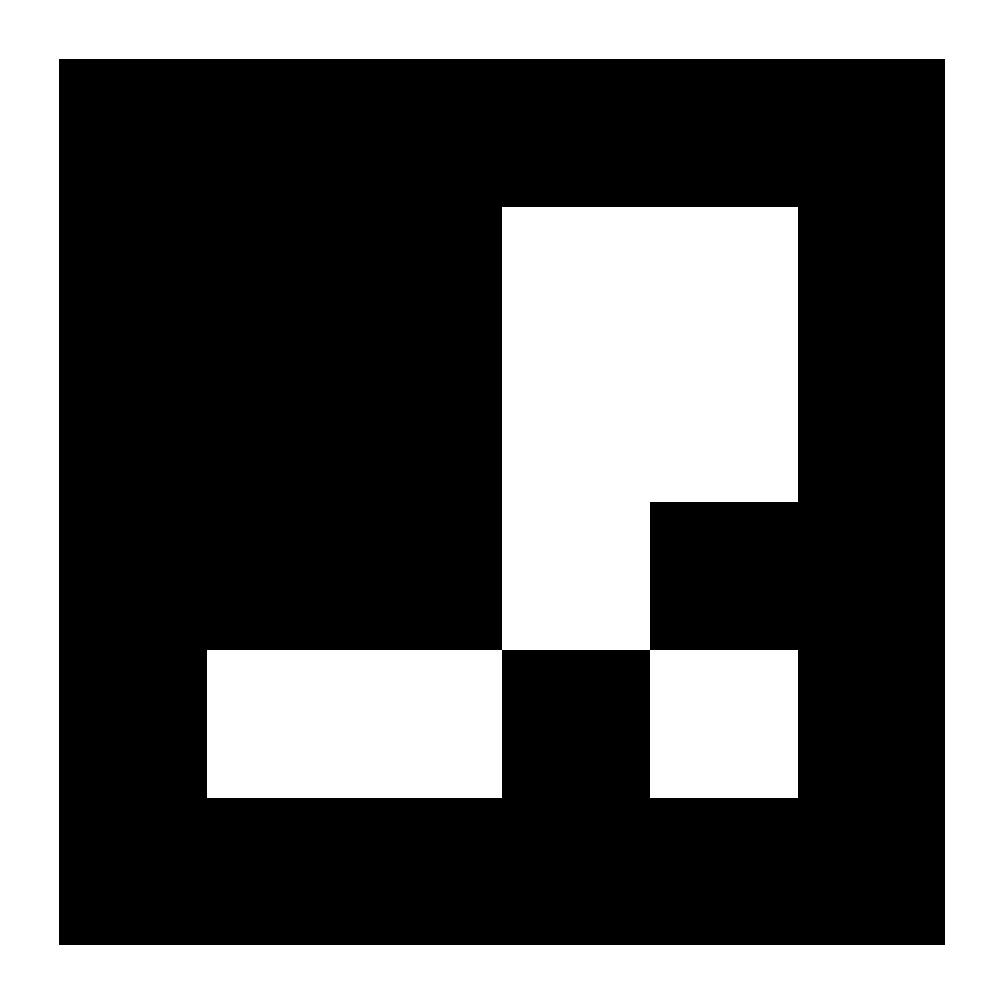
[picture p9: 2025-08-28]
aruco_marker/aruco_4x4_50_75mm/aruco_4x4_50_id2_75mm.png

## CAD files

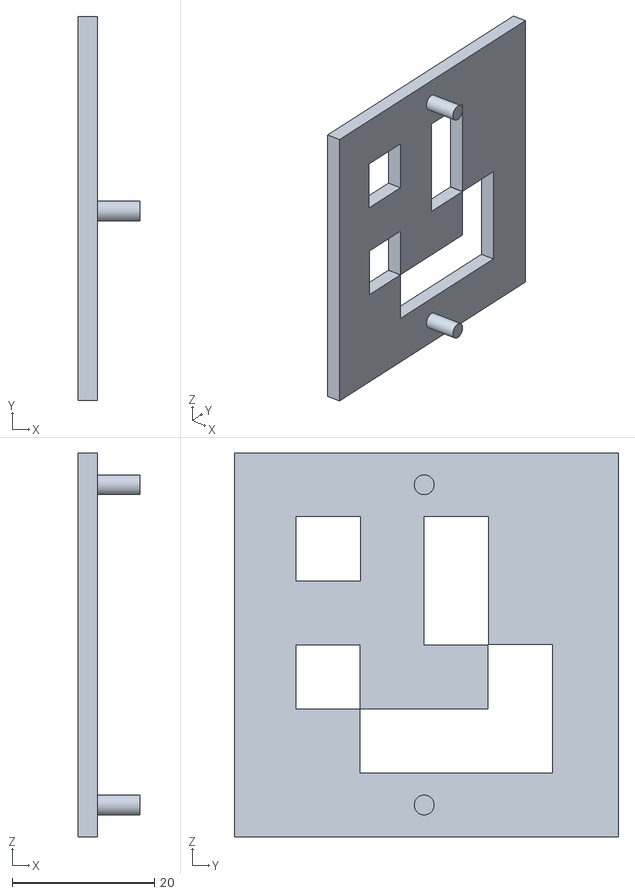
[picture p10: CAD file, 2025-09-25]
stl/TESSERA_1.STL
8.70 x 54.0 x 53.9

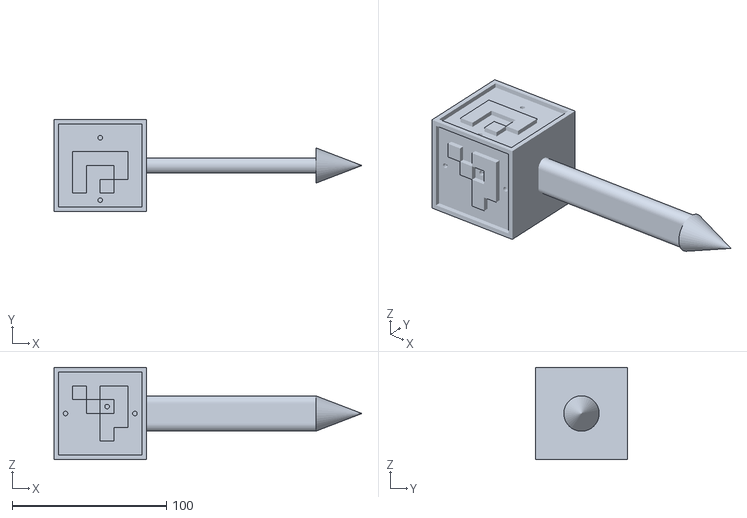
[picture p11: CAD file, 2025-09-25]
stl/PENNA.STL
200.0 x 60.0 x 60.0

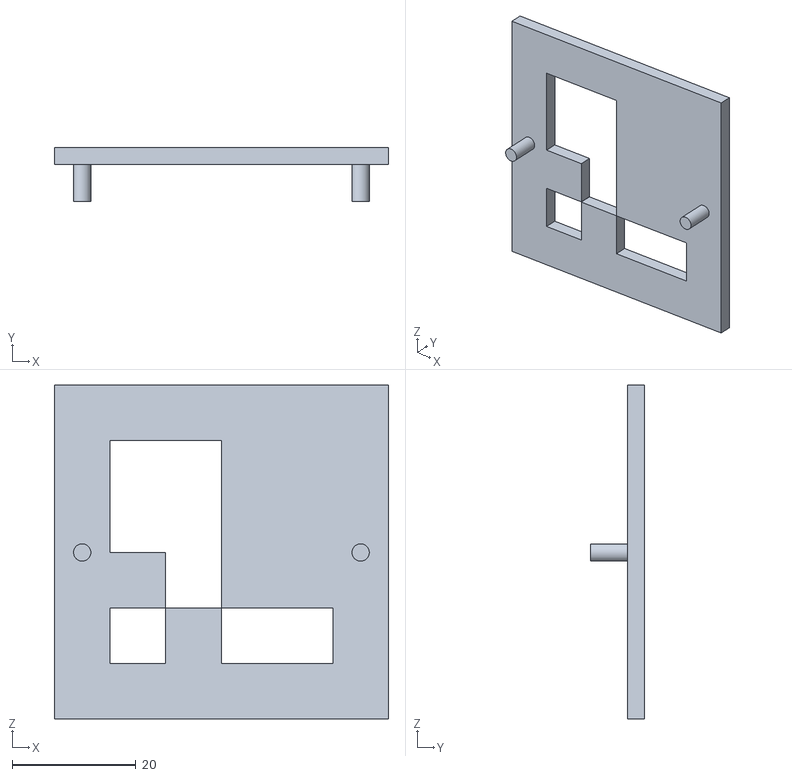
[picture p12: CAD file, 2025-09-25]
stl/TESSERA_4.STL
54.0 x 8.70 x 54.0

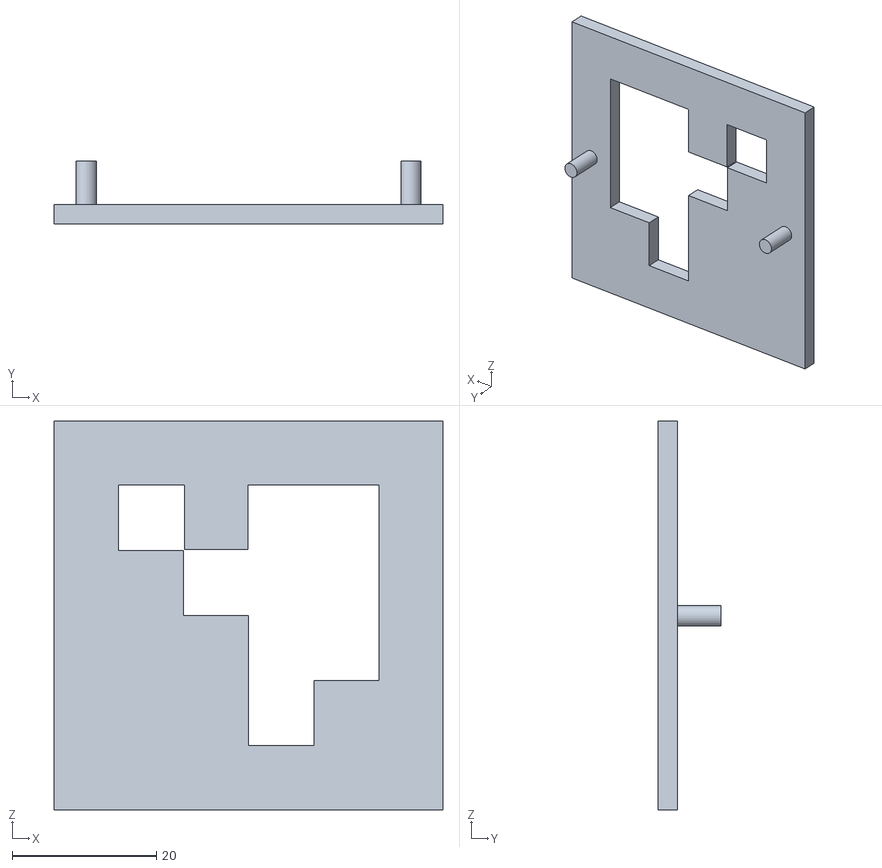
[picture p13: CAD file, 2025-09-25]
stl/TESSERA_5_1.STL
53.9 x 8.70 x 53.9

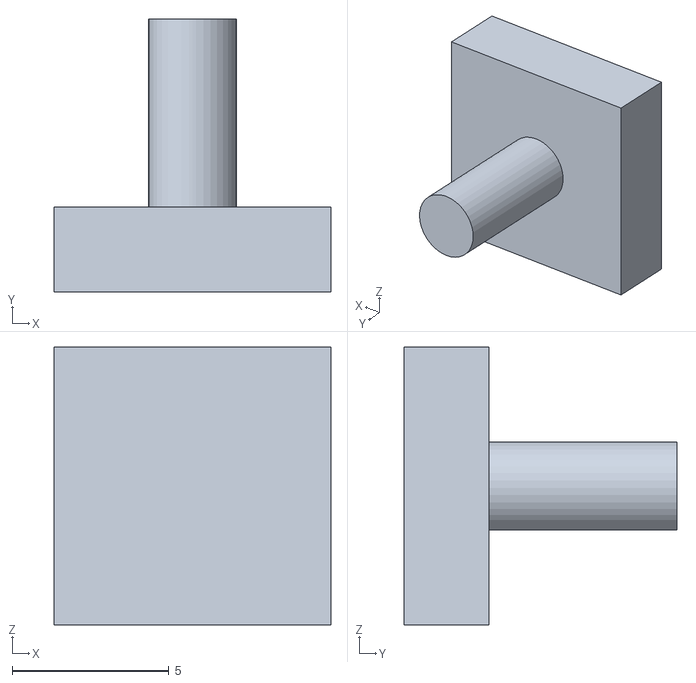
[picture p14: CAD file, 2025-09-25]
stl/TESSERA_5_2.STL
8.84 x 8.70 x 8.87

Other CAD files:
stl/TESSERA_2.STL
stl/TESSERA_3.STL

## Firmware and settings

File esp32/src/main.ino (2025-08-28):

#include <Arduino.h>
#include "config.h"
#include "LedManager.h"
#include "Buttons.h"
#include "BleManager.h"
#include "DisplayManager.h"
#include "UiState.h"

LedManager     LEDS;
Buttons        BTNS;
BleManager     BLE;
DisplayManager OLED;

// per gestione long-press immediata
static bool bleLongHandled = false;
static unsigned long displayOffAtMs  = 0;
static ButtonEvents bBle;
static ButtonEvents bEvt;

void handleBleButton();
void handleEventButton();
void updateIdleLed();

void setup() {
  Serial.begin(115200);

  OLED.begin();
  LEDS.begin(PIN_LED_R, PIN_LED_G, PIN_LED_B, LED_PWM_FREQ, LED_PWM_RES, LED_BRIGHTNESS, /*commonAnode=*/true);
  BTNS.begin(PIN_BTN_BLE, PIN_BTN_EVENT);

  BleManager_initGlobal(&BLE);
  BLE.begin("ESP32-RGB-BLE");

  BLE.onConnect([&]{
    Serial.println("[BLE] Connected");
    LEDS.setState(LedState::CONNECTED);
    OLED.setBleEnabled(true);
    OLED.setUiState(UiState::CONNECTED);
  });

  BLE.onDisconnect([&]{
    Serial.println("[BLE] Disconnected");
    if (BLE.isEnabled()) {
      LEDS.setState(LedState::ADVERTISING);
      OLED.setBleEnabled(true);
      OLED.setUiState(UiState::BLE_ON);
    } else {
      LEDS.setState(LedState::OFF);
      OLED.setUiState(UiState::DISCONNECTED);
      displayOffAtMs = millis() + 1000; // spegni OLED dopo 1s
    }
  });

  BLE.onRx([&](const String& sRaw){
    String s = sRaw; s.trim(); s.toUpperCase();
    Serial.print("[BLE] RX: "); Serial.println(s);
    if (s == "COMPUTATION START")      OLED.setComputing(true);
    else if (s == "COMPUTATION END")   OLED.setComputing(false);
  });

  BLE.startAdvertising();
  LEDS.setState(LedState::ADVERTISING);
  OLED.setBleEnabled(true);
  OLED.setUiState(UiState::BLE_ON);

  Serial.println("== READY ==");
}

void loop() {
  handleBleButton();
  handleEventButton();
  updateIdleLed();
  LEDS.loop();
  OLED.loop();
}

// Gestisce il pulsante BLE e lo spegnimento ritardato dell'OLED.
// Prerequisiti: BTNS, BLE, LEDS e OLED inizializzati e funzione richiamata ad ogni ciclo.
void handleBleButton() {
  if (displayOffAtMs && millis() >= displayOffAtMs) {
    displayOffAtMs = 0;
    OLED.setBleEnabled(false);
  }

  bBle = BTNS.pollBle(BLE_LONG_MS);
  if (bBle.fell) {
    bleLongHandled = false;
    LEDS.setState(LedState::ARMING);
    if (BLE.isEnabled()) OLED.setUiState(UiState::ARMING);
  }

  static unsigned long holdStart = 0;
  if (bBle.isDown && !bleLongHandled) {
    if (!holdStart) holdStart = millis();
    if (millis() - holdStart >= BLE_LONG_MS) {
      bleLongHandled = true; holdStart = 0;
      if (BLE.isEnabled()) {
        if (BLE.isConnected()) BLE.disconnect();
        BLE.stopAdvertising();
        LEDS.setState(LedState::OFF);
        OLED.setUiState(UiState::DISCONNECTED);
        displayOffAtMs = millis() + 1000;
      } else {
        BLE.startAdvertising();
        LEDS.setState(LedState::ADVERTISING);
        OLED.setBleEnabled(true);
        OLED.setUiState(UiState::BLE_ON);
      }
    }
  }
  if (!bBle.isDown) {
    holdStart = 0;
  }

  if (bBle.rose && !bleLongHandled) {
    if (BLE.isConnected()) BLE.disconnect();
    if (BLE.isEnabled()) {
      BLE.startAdvertising();
      LEDS.setState(LedState::ADVERTISING);
      OLED.setBleEnabled(true);
      OLED.setUiState(UiState::BLE_ON);
    }
  }
}

// Gestisce il pulsante EVENT per inviare messaggi START/END e forzare temporaneamente i LED.
// Prerequisito: connessione BLE attiva per l'invio dei messaggi.
void handleEventButton() {
  bEvt = BTNS.pollEvt(1500);

  if (bEvt.isDown && BLE.isConnected()) {
    LEDS.setState(LedState::EVENT_RED);
  }

  if (bEvt.fell) {
    if (BLE.isConnected()) {
      BLE.sendLine("START\n");
      Serial.println("[BLE] TX: START");
      OLED.setUiState(UiState::SENDING);
    } else {
      Serial.println("[BLE] TX IGNORED: not connected");
    }
  }
  if (bEvt.rose) {
    if (BLE.isConnected()) {
      BLE.sendLine("END\n");
      Serial.println("[BLE] TX: END");
      OLED.setUiState(UiState::CONNECTED);
      LEDS.setState(LedState::CONNECTED);
    }
  }
}

// Ripristina lo stato base dei LED quando nessun pulsante è premuto.
// Prerequisito: chiamare prima handleBleButton() e handleEventButton().
void updateIdleLed() {
  if (!bEvt.isDown && !bBle.isDown && !bleLongHandled) {
    if (BLE.isEnabled()) {
      if (BLE.isConnected()) LEDS.setState(LedState::CONNECTED);
      else                   LEDS.setState(LedState::ADVERTISING);
    } else {
      LEDS.setState(LedState::OFF);
    }
  }
}

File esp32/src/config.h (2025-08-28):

// =========================
// File: config.h
// =========================
#pragma once

// ===== I2C OLED =====
#define I2C_SDA_PIN    21    // I2C SDA pin (GPIO 21)
#define I2C_SCL_PIN    22    // I2C SCL pin (GPIO 22)
#define OLED_WIDTH     128   // Display width in pixels
#define OLED_HEIGHT    64    // Display height in pixels
#define OLED_ADDR      0x3C  // I2C address (7-bit)

// ===== RGB LED =====
#define PIN_LED_R      15    // Red LED pin (GPIO 15)
#define PIN_LED_G      5     // Green LED pin (GPIO 5)
#define PIN_LED_B      4     // Blue LED pin (GPIO 4)

// ===== Buttons =====
#define PIN_BTN_EVENT  16    // Event button pin (GPIO 16)
#define PIN_BTN_BLE    17    // BLE button pin (GPIO 17)
#define BLE_LONG_MS    4000  // BLE long-press duration in ms

// ===== PWM =====
#define LED_PWM_FREQ   5000u // PWM frequency in Hz
#define LED_PWM_RES    12u   // PWM resolution in bits
#define LED_BRIGHTNESS 0.05f // LED brightness [0-1]

// ===== UI =====
#define UI_MAIN_TEXT_SIZE 3   // Main text size multiplier

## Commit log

2025-08-27 adding all new feature on esp32 board and dele unsed/unseful code
2025-08-28 feat: add sample dataset and sample-dir option
2025-08-28 refactor: add button handlers
2025-08-28 document button event timeline
2025-08-28 refactor: drop sample-dir option
2025-08-28 Add Basler pypylon camera backend and configuration
2025-08-28 docs: English overview and Basler camera notes
2025-08-28 Add camera configuration options and update docs
2025-08-28 Clean BLE client and replace prints with logger
2025-08-28 add camera info
2025-08-28 adj basler camera compression problem
2025-09-03 adding pen cad file
    [pen_complete.SLDPRT]
2025-09-25 adding new readme.md file and stl of the 3D object
    [PENNA.STL, TESSERA_1.STL, TESSERA_2.STL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]
2025-09-25 new faeture: 1. adj camera open when conncet BLE with device 2. adj capture.py class and method for more clarify 3. pose worker now start work after first image is taken 4. now, during capture/pose w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
2025-10-21 Refactor capture pipeline to stream frames
2025-10-22 Add marker filtering logic and integrate with pose pipeline
2025-10-22 adding new logic for filter marker and adjust error marker

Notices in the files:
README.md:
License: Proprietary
